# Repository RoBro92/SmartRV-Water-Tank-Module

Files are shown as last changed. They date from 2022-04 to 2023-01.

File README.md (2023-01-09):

 

# SmartRV Water Tank Module
**A ESP based water tank module for a Camper/RV**

All feature requests are tracked in the GitHub issue tracker. 
[Feature Requests](https://github.com/RoBro92/feature-requests/issues)

This water tank module is designed to fill a gap in the market for accessible smart water tank monitoring. Other systems such as Pico and Victron do exist however their cost can be prohibitive and require additional components. This module is based on the ESP8266/32 by Espressif & is designed to work standalone or as part of a network to provide accurate and real-time updates for water tank level and temperature. It also provides a relay designed to interface with motorized ball valves or 2/3 wire and will allow remote draining of tanks without having to leave the vehicle. This not only makes filling the tank easier but can also provide emergency frost protection. 

The beauty of the ESP32 is that it can be easily programmed and by having the extra pins on a header you can add your own inputs/outputs to interface with the board. 

The module has been kept as compact as possible and allows for a direct connection to 12v or 24v vehicle systems. 

**If you want to support the development you can purchase the V1 board as a DIY kit or fully assembled V2  from my Ko-Fi Shop [SmartRV Shop](https://ko-fi.com/smartrv/shop)**

## **I have developed two separate versions of this module**

[V1 is THT and is suitable for at-home soldering](#tht)

[V2 is the final retail product and comes pre assembled inclduing software to allow easy OTA upload](#smd)

### THT

# **V1.3**
This release represents the final revision any further changes should be requested in the [Feature Requests](https://github.com/RoBro92/feature-requests/issues) section. It has been updated to include the design schematic and PCB layout. I will stock a number of these boards to be assembled by yourself and can also include supporting documentation. This device can also be supplied assembled if required. 

# **Changes**
- [x] - Updated to V1.3 final. 

# **Features**
- [x] - Removeable WemosD1 chip (ESP8266)
- [x] - Onboard power regulation
- [x] - Variable voltage input 8v-36v
- [x] - Compact form factor
- [x] - DS18b20 temperature sensor
- [x] - Resistive water level sensor
- [x] - 10A relay for water valve control
- [x] - LED Indicator for Power-ON
- [x] - Added reverse polarity protection
- [x] - Added LED indicators for power and relay
- [x] - Updated repository with Gerber production files

# **Images**
<table>
  <tr>
    <td>3D Model</td>
  </tr>
  <tr>
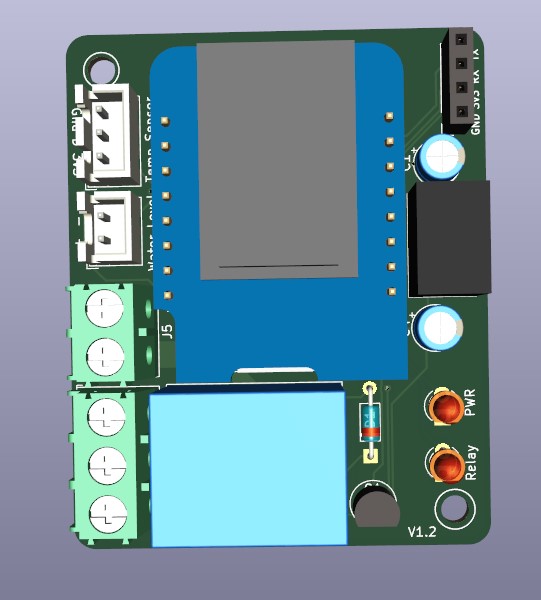
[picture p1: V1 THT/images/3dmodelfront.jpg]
    <td></td>
  </tr>
 
 </table>
<table>
  <tr>
         <td>Schematic</td>
     <td>PCB Layout</td>

  </tr>
  <tr>
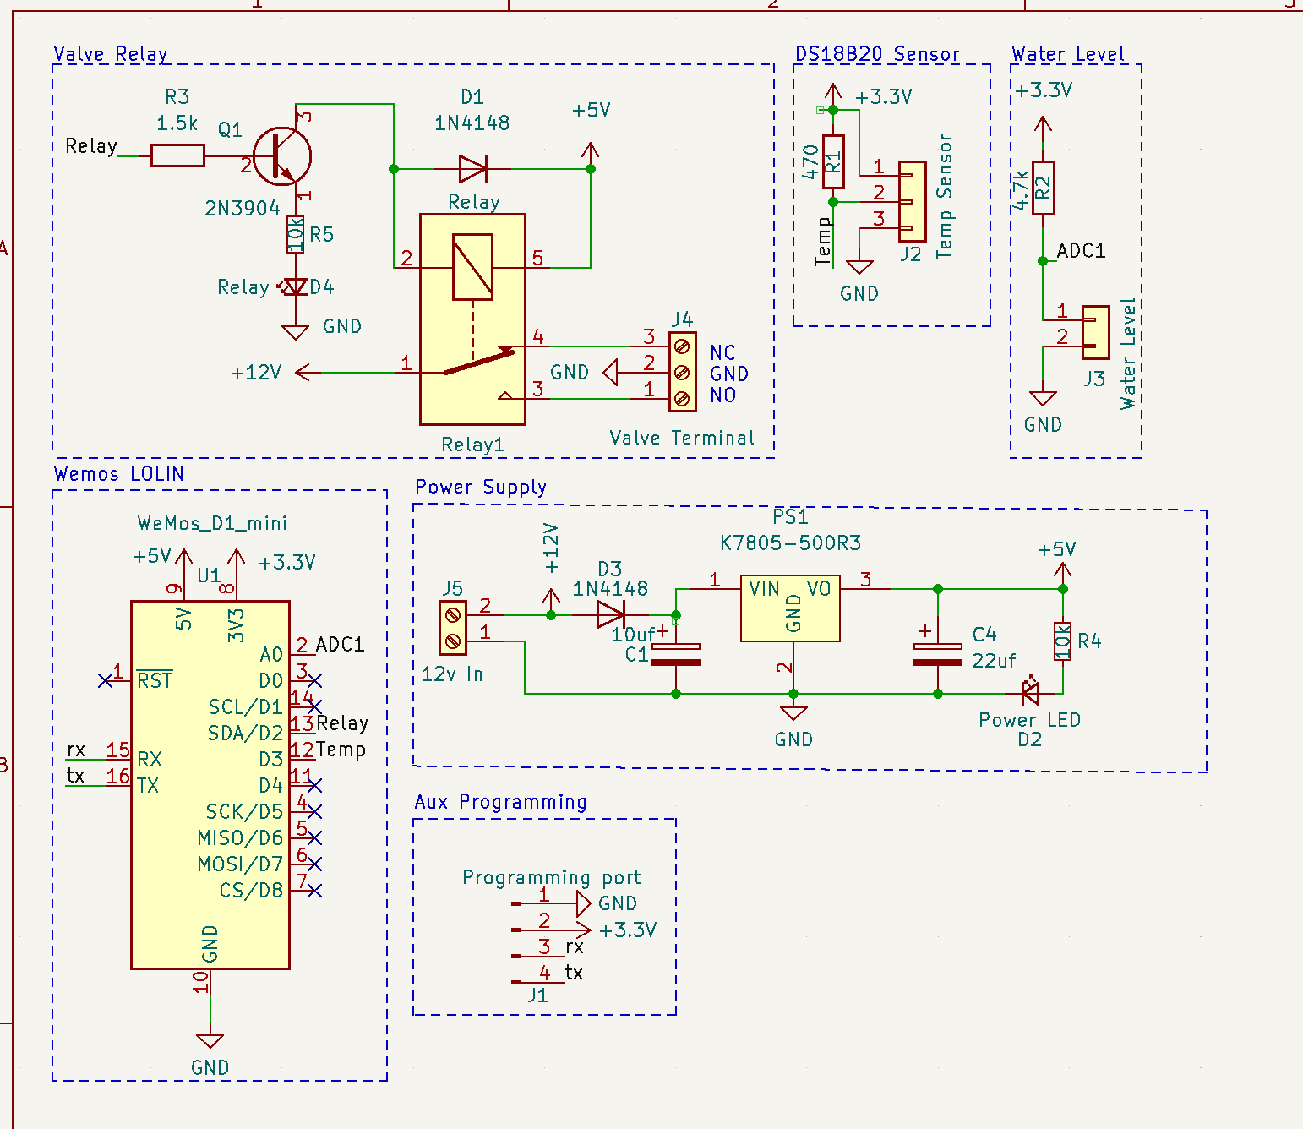
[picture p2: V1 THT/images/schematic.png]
   <td></td>
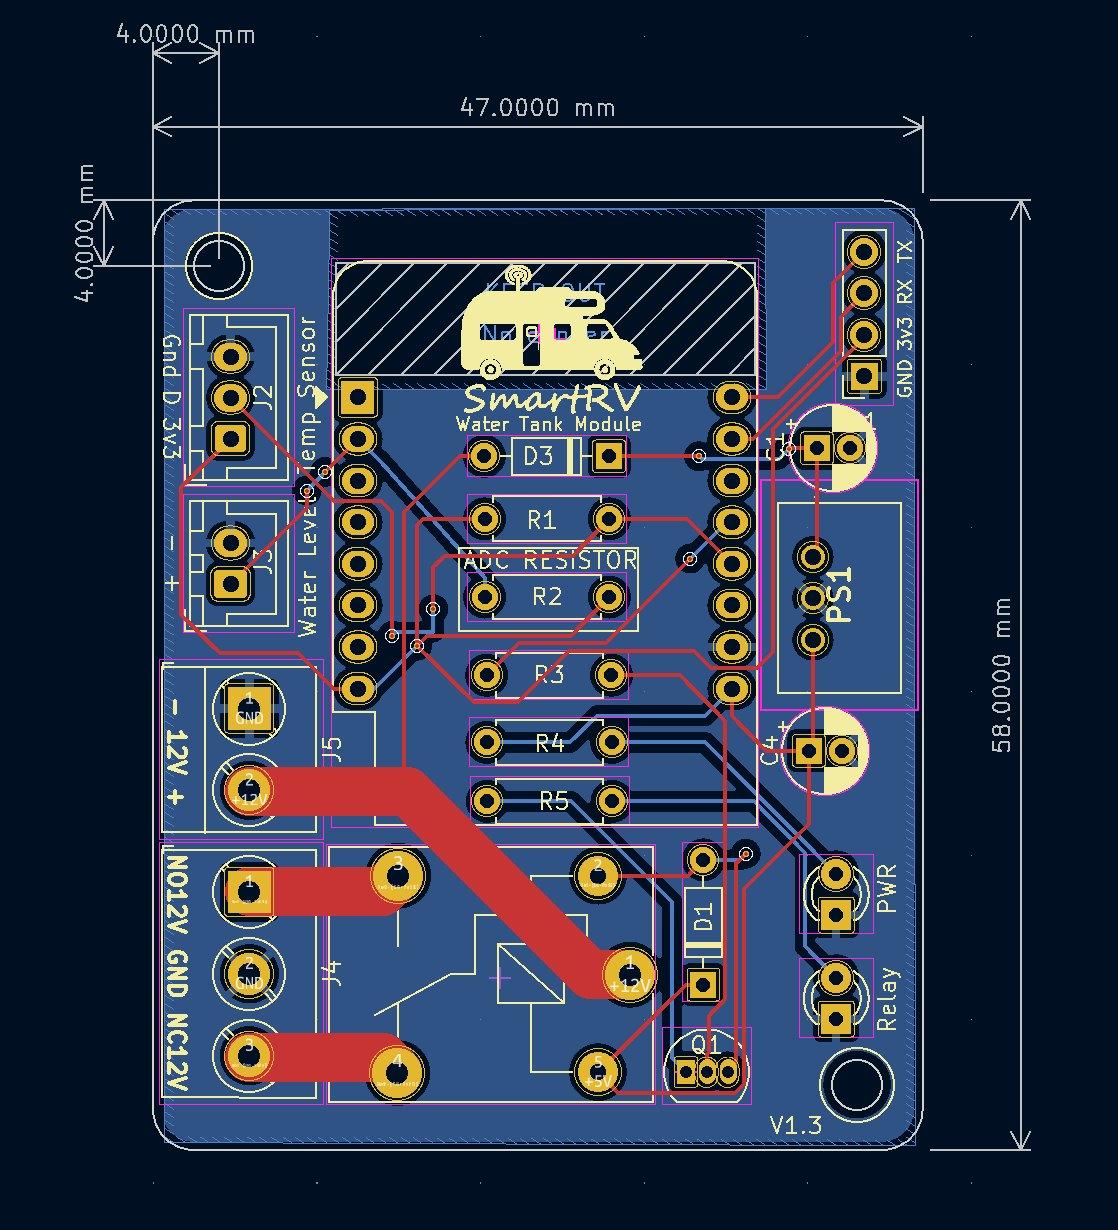
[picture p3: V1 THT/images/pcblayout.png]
   <td></td>    
  </tr>
 </table>

<table>
  <tr>
    <td>PCB Front v1.3</td>
     <td>PCB Rear v1.3</td>
  </tr>
  <tr>
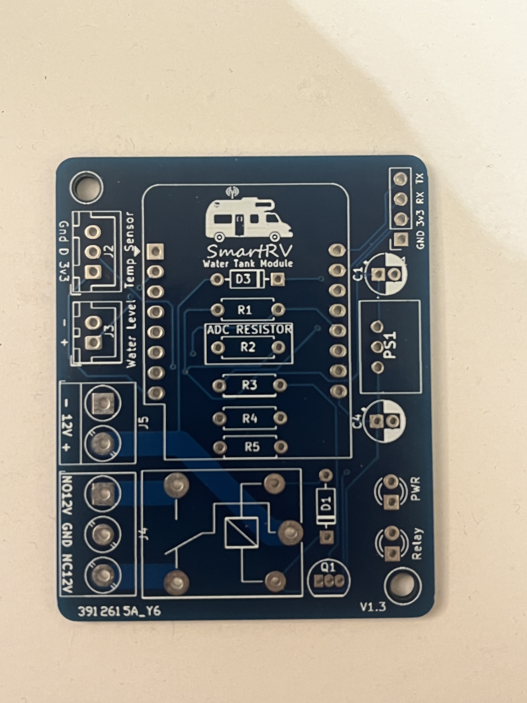
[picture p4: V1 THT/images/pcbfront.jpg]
    <td></td>
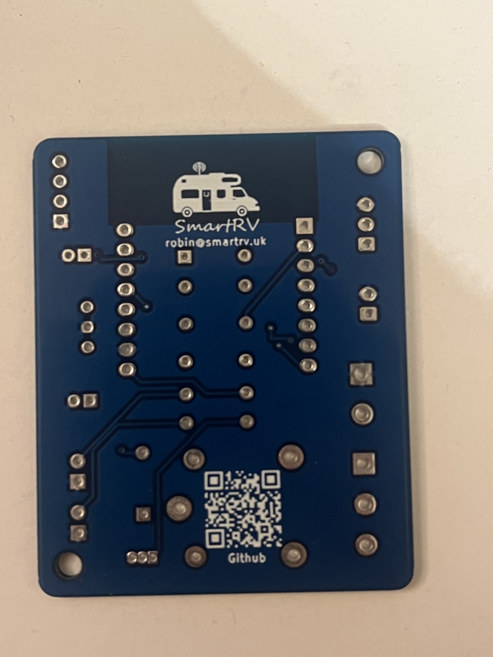
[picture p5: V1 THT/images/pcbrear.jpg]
    <td></td>
  </tr>
 </table>

# **WARNING**
This board does not have any fuse protection as such this must be provided externally.

___

### SMD

# **V2.1**
This version is the final retail production of the SmartRV Water Tank Module. It comes with many improvements over the V1 version. 
Built primarily with surface mounted components this version is able to be as compact as possible while also retaining a full feature set. 
This board will be available to buy from my Kofi Shop.

It will also feature an ESP32 Module for several reasons;
- Bluetooth connection with AIO board to act as an additional wireless tank sensor
- Lower power consumption if being used with a battery
- Newer technology

# **Changes This Version**
- [x] - Added 3D printed case

# **Features**
- [x] - ESP32-C3-Mini
- [x] - Onboard power regulation
- [x] - Variable voltage input 8v-36v
- [x] - Compact form factor
- [x] - DS18b20 temperature sensor input
- [x] - Resistive water level sensor input with variable resistance selection via THT resistor
- [x] - 10A relay for water valve control 
- [x] - Reverse polarity protection
- [x] - External display provided via TX/RX for Nextion display
- [x] - Reverse polarity protection
- [x] - Expansion header for user customisation
- [x] - Bluetooth communication built into ESP32 module

# **Planned Changes**

- [ ] - Bluetooth app
- [ ] - Onboard USB programmer
- [ ] - Manual Override switch

# **Images**
<table>
  <tr>
    <td>Schematic</td>
     <td>PCB Layout</td>
  </tr>
  <tr>
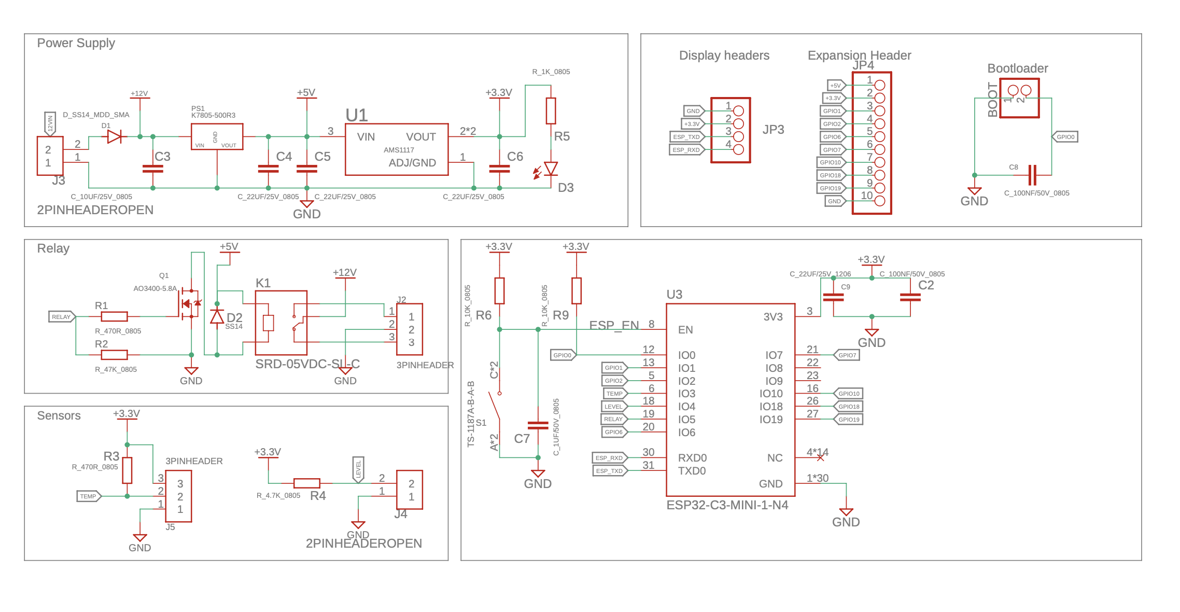
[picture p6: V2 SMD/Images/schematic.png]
    <td></td>
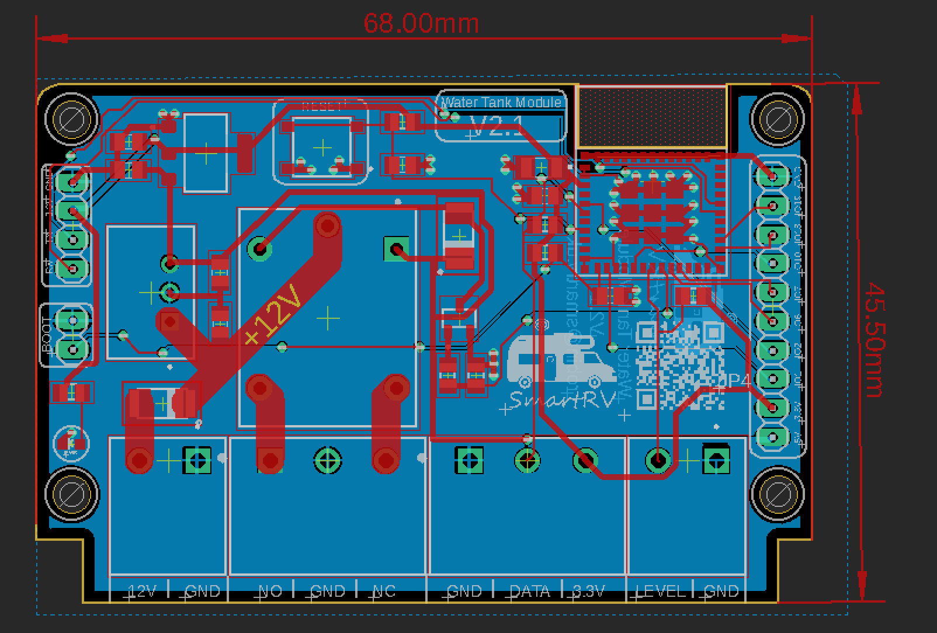
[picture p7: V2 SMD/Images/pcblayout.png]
    <td></td>
  </tr>
 </table>

<table>
  <tr>
    <td>3D Model Front</td>
     <td>3D Model Rear</td>
  </tr>
  <tr>
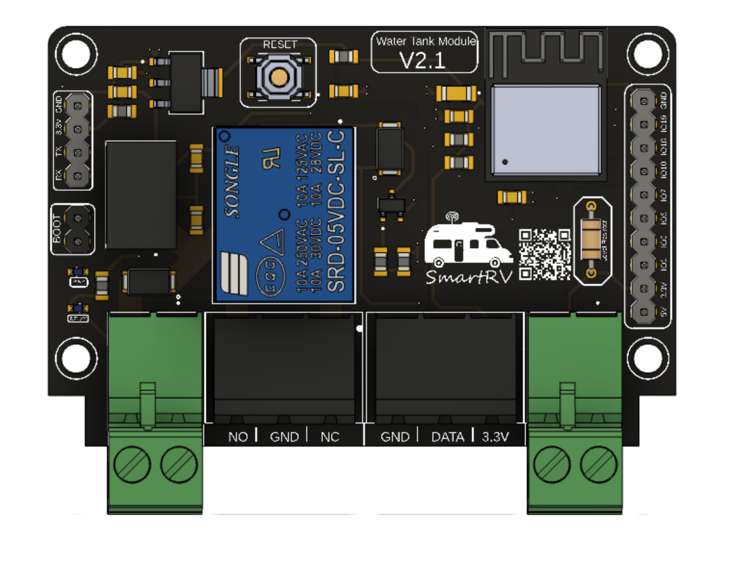
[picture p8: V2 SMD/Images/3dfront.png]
    <td></td>
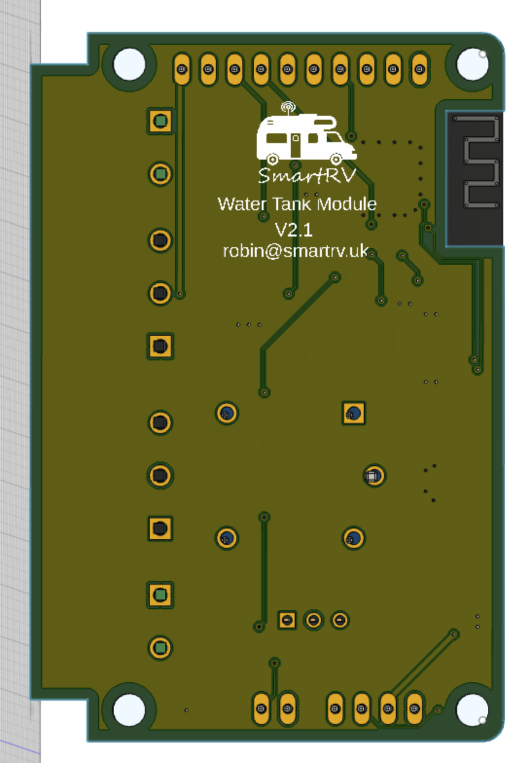
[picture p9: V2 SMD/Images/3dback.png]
    <td></td>
  </tr>
 </table>

<table>
  <tr>
    <td>Case</td>
     <td>Case Inside</td>
  </tr>
  <tr>
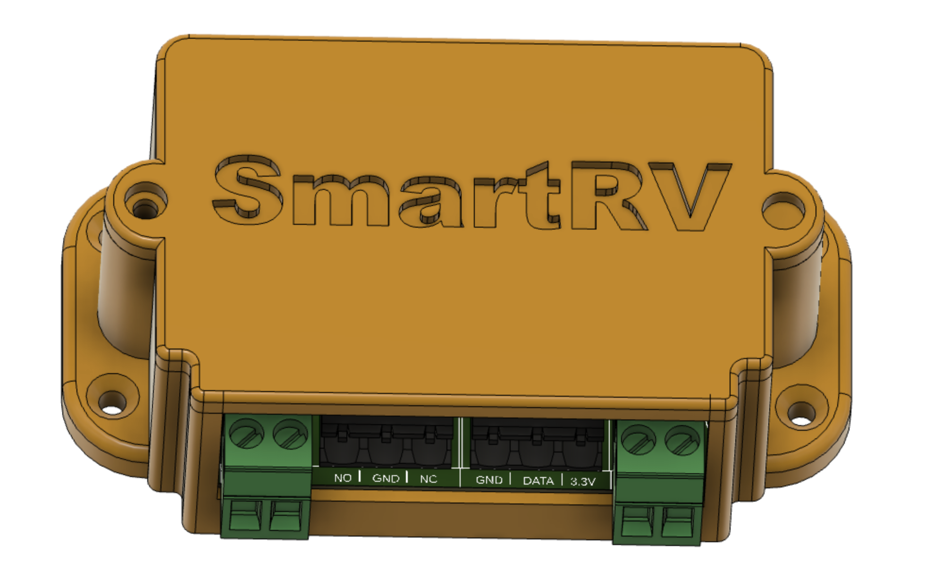
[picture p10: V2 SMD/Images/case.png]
    <td></td>
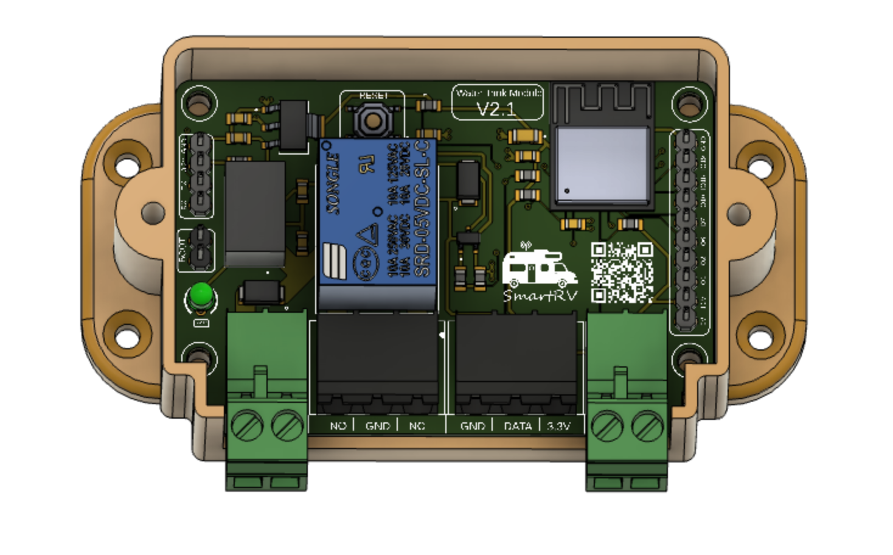
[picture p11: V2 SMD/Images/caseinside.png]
    <td></td>
  </tr>
 </table>

# **WARNING**
This board does not have any fuse protection as such this must be provided externally.

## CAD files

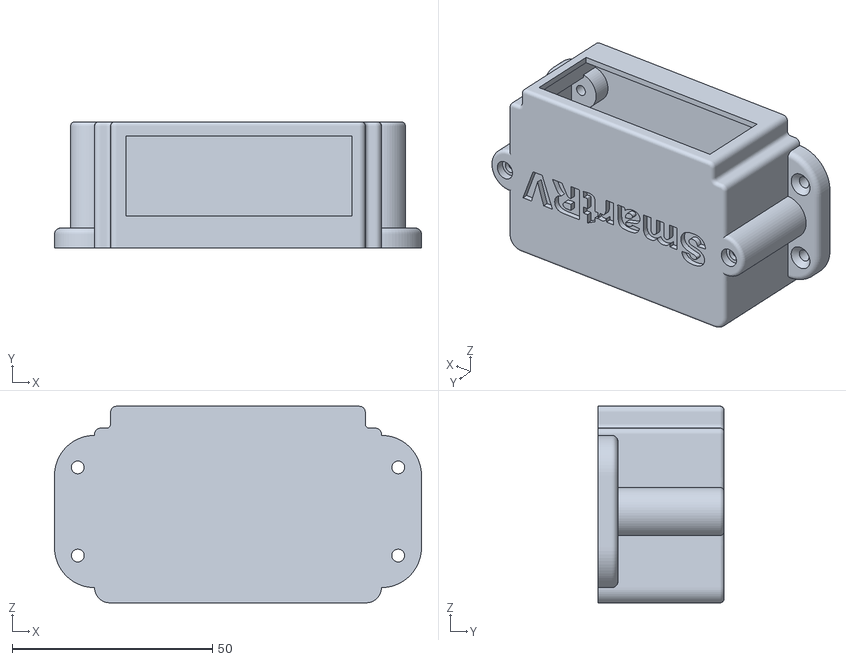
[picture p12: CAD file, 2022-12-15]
V2 SMD/Case Files/Case v4.stl
91.6 x 31.5 x 49.1

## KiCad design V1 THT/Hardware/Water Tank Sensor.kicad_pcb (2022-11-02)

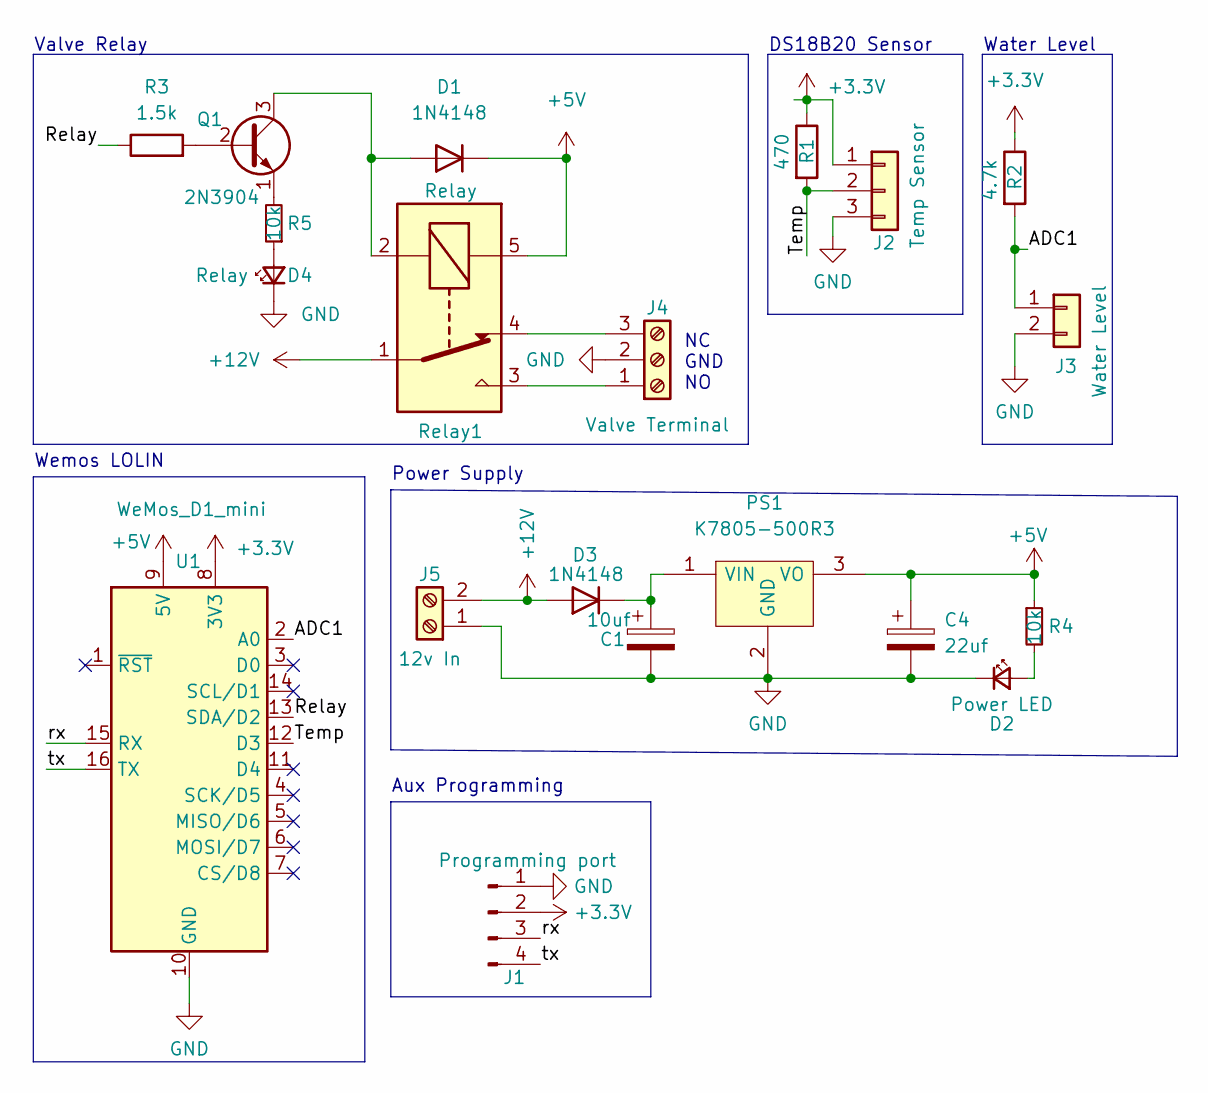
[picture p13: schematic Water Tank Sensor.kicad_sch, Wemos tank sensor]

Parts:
C1: 10uf; CP_Radial_D5.0mm_P2.00mm
C4: 22uf; CP_Radial_D5.0mm_P2.00mm
D1, D3: 1N4148; D_DO-35_SOD27_P7.62mm_Horizontal
D2: Power LED; LED_D3.0mm
D4: Relay; LED_D3.0mm
J1: Programming port; PinSocket_1x04_P2.54mm_Vertical
J2: Temp Sensor; JST_XH_B3B-XH-A_1x03_P2.50mm_Vertical
J3: Water Level; JST_XH_B2B-XH-A_1x02_P2.50mm_Vertical
J4: Valve Terminal; TerminalBlock_Phoenix_PT-1,5-3-5.0-H_1x03_P5.00mm_Horizontal
J5: 12v In; TerminalBlock_Phoenix_PT-1,5-2-5.0-H_1x02_P5.00mm_Horizontal
PS1: K7805-500R3; K7805500R3; Manufacturer_Part_Number K7805-500R3
Q1: 2N3904; TO-92_Inline
R1: 470; R_Axial_DIN0207_L6.3mm_D2.5mm_P7.62mm_Horizontal
R2: 4.7k; R_Axial_DIN0207_L6.3mm_D2.5mm_P7.62mm_Horizontal
R3: 1.5k; R_Axial_DIN0207_L6.3mm_D2.5mm_P7.62mm_Horizontal
R4, R5: 10k; R_Axial_DIN0207_L6.3mm_D2.5mm_P7.62mm_Horizontal
Relay1: Relay; Relay_SPDT_SANYOU_SRD_Series_Form_C
U1: WeMos_D1_mini; WEMOS_D1_mini_light

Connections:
+3V3: J1.2, J2.1, R1.1, R2.1, U1.8 (3V3)
+5V: C4.1, D1.1 (K), PS1.3 (VO), R4.1, Relay1.5, U1.9 (5V)
+12V: D3.2 (A), J5.2, Relay1.1
/ADC1: J3.1, R2.2, U1.2 (A0)
/Relay: R3.1, U1.13 (SDA/D2)
/Temp: J2.2, R1.2, U1.12 (D3)
/rx: J1.3, U1.15 (RX)
/tx: J1.4, U1.16 (TX)
GND: C1.2, C4.2, D2.1 (K), D4.1 (K), J1.1, J2.3, J3.2, J4.2, J5.1, PS1.2 (GND), U1.10 (GND)
unnamed: C1.1, D3.1 (K), PS1.1 (VIN)
unnamed: D1.2 (A), Q1.3 (C), Relay1.2
unnamed: D2.2 (A), R4.2
unnamed: D4.2 (A), R5.1
unnamed: J4.1, Relay1.3
unnamed: J4.3, Relay1.4
unnamed: Q1.1 (E), R5.2
unnamed: Q1.2 (B), R3.2

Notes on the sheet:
Aux Programming
Power Supply
DS18B20 Sensor
NC GND NO
Water Level
Valve Relay
Wemos LOLIN

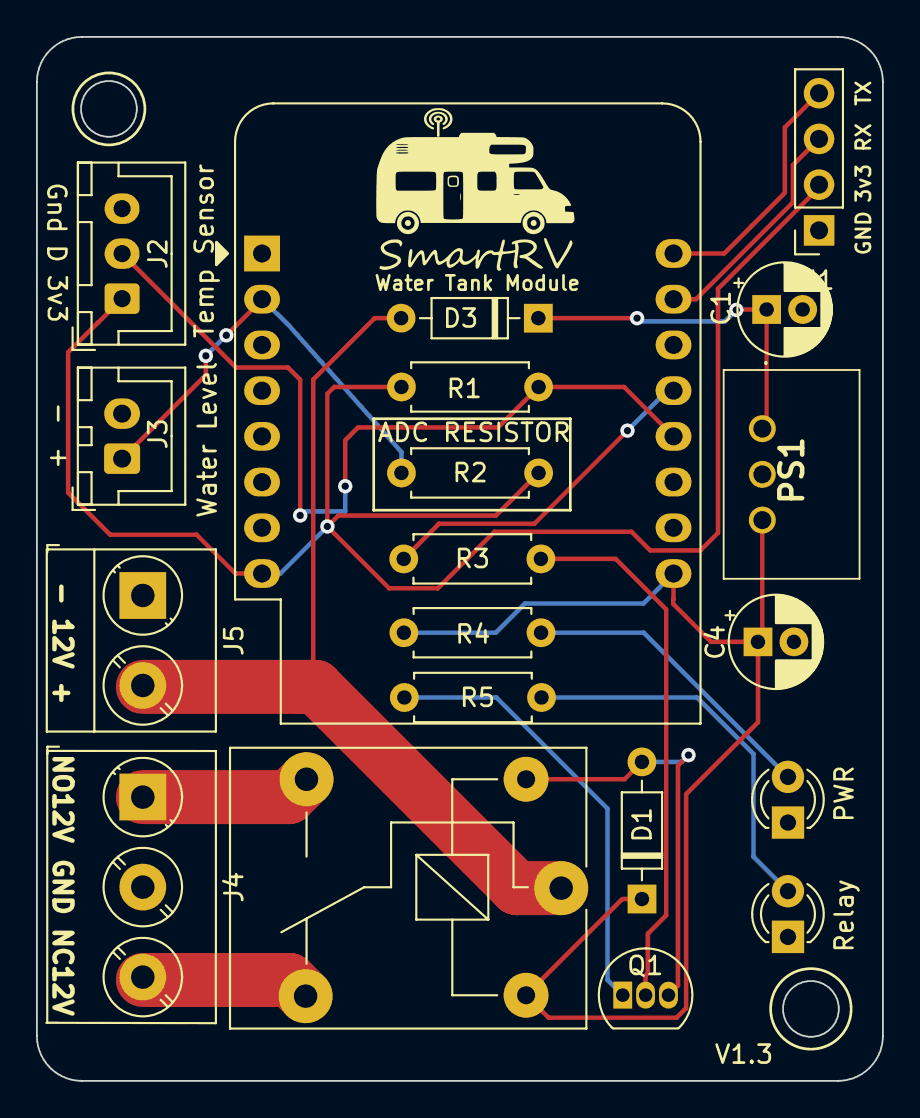
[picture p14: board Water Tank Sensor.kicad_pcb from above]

Board: 2 copper layers, 47.0 x 58.0 mm, 20 parts (0 on the bottom side), 17 nets.

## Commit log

2022-02-17 upload pcb images
    Images of v1.0 pcb uploaded
2022-02-17 Update README.md
    Added images for v1.0 pcb
2022-02-23 Images for schematic and PCB uploaded
2022-02-23 Schematic updated
2022-03-01 Added schematic and pcb layout files and included documentation for SMD V2
    [Water Tank Sensor V2.kicad_pcb, Water Tank Sensor V2.kicad_sch, Water Tank Sensor.kicad_pcb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]
2022-03-01 Schematic update
    [Water Tank Sensor V2.kicad_pcb]
2022-03-02 Added schematic image
    [Water Tank Sensor V2.kicad_pcb, Water Tank Sensor V2.kicad_sch]
2022-03-04 Added completed PCB layout for V2SMD with images
    [Water Tank Sensor V2.kicad_pcb, Water Tank Sensor V2.kicad_sch]
2022-04-21 Updated files to v1.1 incnluding images annotating resistor to vary depending on ADC sensor.
    [Water Tank Sensor.kicad_pcb, Water Tank Sensor.kicad_sch]
2022-04-21 Updated files for V1.1 including images
    [Water Tank Sensor V2.kicad_pcb, Water Tank Sensor V2.kicad_sch, Water Tank Sensor.kicad_pcb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]
2022-04-27 Updated v1.2
    [Water Tank Sensor.kicad_pcb, Water Tank Sensor.kicad_sch]
2022-10-09 New Update SMD to V2.1
    Updated SMD version, Now using Autodesk Fusion360 for PCB design, updated images and readme. Production files to follow once tested
    [Water Tank Sensor V2.kicad_pcb, Water Tank Sensor V2.kicad_sch]
2022-10-11 Update to SMD version
    Including case design and revised sections
2022-10-25 Updated V1 THT to V1.3
    THT version updated to final model with revisions. No further changes will be made to V1. Boards available to purchase from store
    [Water Tank Sensor.kicad_pcb]
2022-12-15 Image update
    Updated images for v1.3
    [Case v4.stl]
2023-01-09 Create Water Tank Sensor-2023-01-09_215214.zip
